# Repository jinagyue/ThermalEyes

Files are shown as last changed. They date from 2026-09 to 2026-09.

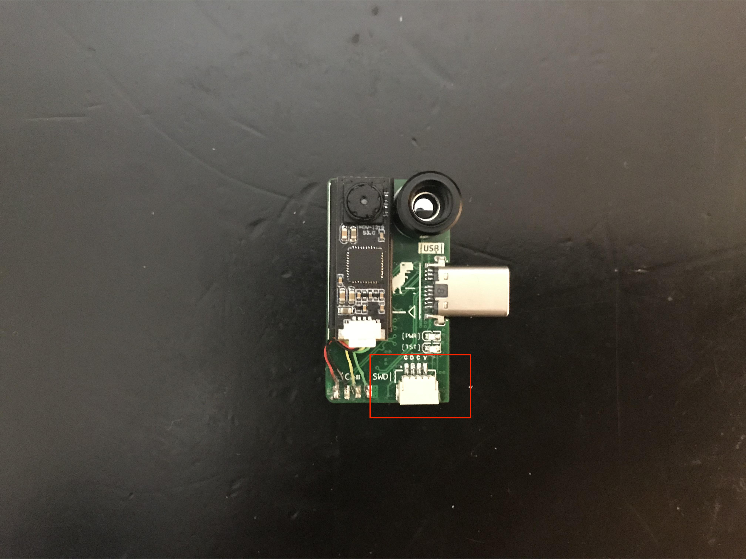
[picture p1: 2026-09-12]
firmware/Resource/port.png

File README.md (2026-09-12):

# ThermalEyes (双目手机红外热成像系统)

<div align="center">







**一款集可见光与远红外热辐射于一体的双光谱手机热成像开源套件**  
*支持实时双光图像融合、视差校准补偿、伪彩映射与高低温动态跟踪*

</div>

---

## 📖 项目简介 (Overview)

**ThermalEyes** 是一个软硬件结合的全栈开源项目。项目通过外接便携式双目模组（可见光摄像头 + MLX90640 远红外传感器），在 Android 移动端实现双光融合成像。借助 C++ (OpenCV) 原生算法，将可见光的丰富高频细节与红外热辐射轮廓实时叠加，解决红外分辨率低、轮廓模糊的问题。

本项目采用 **Monorepo（单一大仓库）** 结构，包含**下位机固件**、**Android 客户端应用**以及**3D 打印外壳模型**。

---

## 🗂️ 仓库目录结构 (Repository Structure)

```text
ThermalEyes/
├── software/                 # Android 手机客户端源码
│   ├── app/                  # 主 APP 模块 (Java UI + NDK C++ 融合算法)
│   ├── OpenCV/               # OpenCV Android SDK 模块
│   └── build.gradle          # Gradle 构建配置
│
├── firmware/                 # STM32 下位机桥接固件源码
│   ├── Core/                 # STM32 主逻辑与系统配置
│   ├── Hardware/             # MLX90640 I2C 驱动与温度解析算法
│   ├── USB_DEVICE/           # USB CDC 虚拟串口通讯协议
│   └── thermal_bridge.ioc    # STM32CubeMX 工程配置文件
│
├── hardware/                 # 硬件外壳结构设计
│   ├── *.STL                 # 3D 打印成型切片模型 (顶盖与底座)
│   └── *.STEP                # CAD 三维结构工程源文件
│
├── .gitignore                # 统合过滤编译输出与环境配置
└── README.md                 # 项目说明文档
```

---

## 🛠️ 系统架构与数据链路 (System Architecture)

```mermaid
graph LR
    subgraph HW["硬件端 (Hardware)"]
        MLX["MLX90640 红外传感器<br/>(32x24 热阵列)"] -->|I2C 400kHz| MCU["STM32F411CEU6<br/>(固件: firmware)"]
        MCU -->|USB CDC 数据流| HUB["Type-C OTG 接口"]
        CAM["可见光 UVC 摄像头模组"] -->|USB Video| HUB
    end

    subgraph APP["手机端 (Android / software)"]
        HUB --> USB_MGR["Android USB Host"]
        USB_MGR -->|UVCAndroid 协议| FRAME_CAM["可见光视频帧"]
        USB_MGR -->|UsbSerial 串口驱动| FRAME_IR["红外原始温度帧"]
        
        FRAME_CAM --> FUSION["C++ OpenCV 图像融合引擎<br/>(视差校准 + 高频增强 + 伪彩映射)"]
        FRAME_IR --> FUSION
        FUSION --> GL_VIEW["实时 HUD 显示 & 高低温跟踪"]
    end
```

---

## 📋 硬件物料清单 (Hardware BOM)

| 部件类别 | 型号 / 规格 | 说明 |
| :--- | :--- | :--- |
| **主控芯片** | STM32F411CEU6 (BlackPill 或定制板) | 运行 `firmware/` 固件，解析 MLX90640 并通过 USB CDC 上传 |
| **红外热传感器** | MLX90640 (常用 55° 或 110° 视场角) | 32×24 像素阵列远红外传感器，I2C 通讯 |
| **可见光相机** | UVC 协议免驱 USB 摄像头模组 | 与红外传感器等间距并排安装 |
| **连接外壳** | 3D 打印外壳 (`hardware/` 目录) | 建议使用 PETG 或树脂 3D 打印，双镜头固定 |
| **通讯接口** | Type-C 数据线 / OTG 转换器 | 连接至 Android 手机 USB-C 口 |

---

## 🚀 快速上手与复刻指南 (Getting Started)

### 1. 固件烧录 (`firmware/`)
- **开发工具**：STM32CubeIDE (推荐 v1.13.0+)
- **烧录接口**：采用 **SH1.0 4-Pin SWD 接口**，线序如下（供电 3.3V）：
  ```text
  | GND | SWDIO | SWCLK | 3.3V |
  ```
- **编译与烧录**：
  1. 使用 STM32CubeIDE 打开 `firmware/` 目录作为工程。
  2. 连接 ST-Link 或 DAP-Link 调试器。
  3. 执行 `Project -> Build Project`，点击 Run/Debug 将固件烧录进 STM32。

### 2. Android 客户端构建 (`software/`)
- **开发工具**：Android Studio (推荐 Bumblebee 或更新版本)
- **依赖环境**：Android SDK、NDK (Side-by-side)、CMake
- **构建步骤**：
  1. 使用 Android Studio 打开 `software/` 目录。
  2. 等待 Gradle 同步完成（若提示 NDK/CMake 缺失请根据提示在 SDK Manager 中安装）。
  3. 连接支持 OTG 功能的 Android 手机，开启开发者选项与 USB 调试。
  4. 点击 **Run 'app'** 安装至手机。

### 3. 外壳制作 (`hardware/`)
- 使用 3D 打印切片软件（如 Cura、Bambu Studio、PrusaSlicer）导入 `hardware/` 目录下的 `.STL` 文件：
  - `binocular_thermal_imager - bottom-2.STL`（下盖）
  - `binocular_thermal_imager - top-2.STL`（上盖）
- **打印建议**：层高 0.16mm - 0.2mm，填充率 30% 以上。

---

## ✨ 核心功能与使用特性 (Features)

1. **双光谱实时融合**：
   - 采用拉普拉斯/高斯滤波提取可见光高频轮廓，与热分布底图融合，实现细节丰富的高清热成像。
2. **多模式切换**：
   - 支持纯可见光、纯红外热成像、轮廓画中画、双光叠加融合模式。
3. **视差动态校准 (Parallax Correction)**：
   - 算法内置水平与垂直平移补偿调节，消除不同测距下双镜头物理间距造成的图像重影。
4. **多样化伪彩映射 (Colormaps)**：
   - 支持 Ironbow（铁红）、Rainbow（彩虹）、JET、White Hot、Black Hot 等主流热成像调色板。
5. **动态高低温标记**：
   - 实时自动检测全屏最高温、最低温坐标，并自动跟随绘制十字准星与数值。

---

## 📄 许可证 (License)

本项目基于 [MIT License](software/LICENSE) 开源。欢迎 Star、Fork 并提交 Pull Request！

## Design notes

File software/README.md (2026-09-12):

# ThermalEyes
双目热成像手机APP，用于获取摄像头数据和热成像数据，并进行融合显示

## Environment
Android Studio Bumblebee | 2021.1.1 Patch 2

## Test Platform
meizu 18s

## Depends on
 - [UVCAndroid](https://github.com/shiyinghan/UVCAndroid)
 - [UsbSerial](https://github.com/felHR85/UsbSerial)

## Structure
```
 |- app  // APP Demo, 冒烟基于该app
 |- app2 // 存在问题，未启用
```

## Feature
1. 获取热成像数据
2. 获取摄像头数据
3. 图像融合
4. 图像显示
5. 融合模式切换
6. 伪彩颜色空间切换
7. 算法参数调整（视差补偿、高频占比）
8. 高低温跟踪和显示
9. 显示下位机log
10. 保存用户配置(TODO)
11. 热成像帧率调整
12. 拍照(TODO)
13. 后期分析(TODO)
    
## Development
由于 Android 手机 USB 端口被占用，需要使用 WIFI 无线调试，开启方法如下：

1. 使用 USB 线将手机连接电脑，开启USB调试，在 Android Studio 中的 Terminal 窗口输入`adb devices`能看到设备
2. 保证电脑和手机在同一个局域网下，然后输入命令`adb tcpip 5555`开启手机远程调试功能
3. 找到手机的IP地址，执行命令`adb connect <IP>`进行远程连接
4. 最后断开手机USB连接，执行命令`adb devices`能看到设备既已经连接
    
## Change Log
20231128 
 - 完成基本功能

20231209
 - 集成OpenCV
 - 改用高斯模糊提取高频信息
 - 增加视差调整功能

20231221
 - 增加高低温跟踪
 - 增加菜单栏算法参数配置
 - 屏幕旋转锁定
 - 修改下位机通信协议

20230203
 - 增加热成像帧率调整选项
 - camera连接时打开热成像，删除打开关闭按钮
 - 优化软件界面
 - 适配3d外壳的视差调整
 - 修复第二次插入闪退问题

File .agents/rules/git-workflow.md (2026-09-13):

# Git 更新规范 (Git Workflow Rules)

## 核心规则 (Mandatory Rule)
**每次处理、修改代码或完成问题排查后，都必须更新 Git！**
Whenever any code is processed, bug fixed, or feature modified, the agent MUST update Git.

## 执行流程 (Execution Steps)
1. **核对改动**：运行 `git status` 与 `git diff` 审查修改内容，确保无多余临时文件或不相关改动。
2. **暂存文件**：执行 `git add <files>` 暂存修改及新增的相关文件。
3. **清晰提交**：执行 `git commit -m "<type>(<scope>): <message>"`，使用清晰的中文或英文语义化提交信息。
4. **工作区检查**：确认 `git status` 确保工作区状态符合预期。

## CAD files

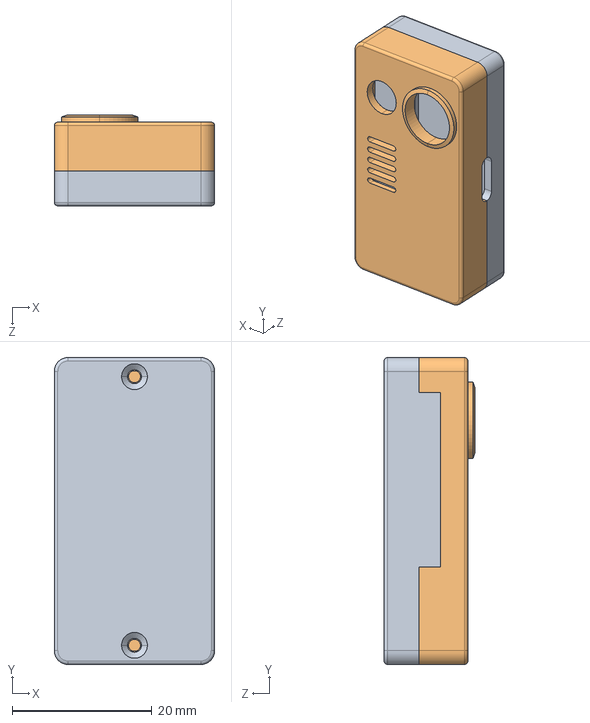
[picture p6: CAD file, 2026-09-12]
hardware/binocular_thermal_imager.STEP
23.0 x 44.0 x 13.0 mm
bottom
top

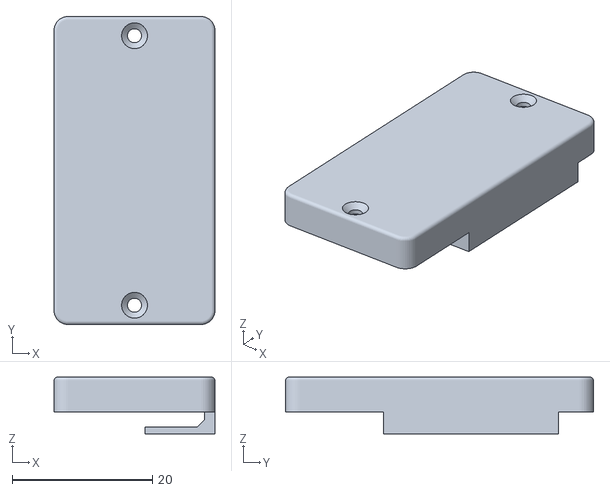
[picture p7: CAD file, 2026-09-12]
hardware/binocular_thermal_imager - bottom-2.STL
23.0 x 44.0 x 8.10

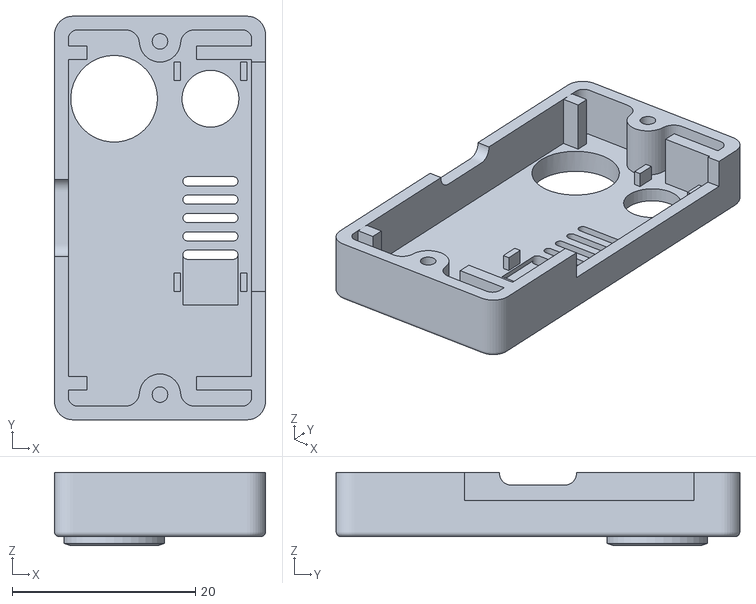
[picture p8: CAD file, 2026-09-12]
hardware/binocular_thermal_imager - top-2.STL
23.0 x 44.0 x 8.00

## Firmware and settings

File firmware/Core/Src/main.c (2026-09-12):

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
/* Includes ------------------------------------------------------------------*/
#include "main.h"
#include "i2c.h"
#include "usart.h"
#include "usb_device.h"
#include "gpio.h"

/* USER CODE BEGIN Includes */
#include "mlx90640_adapter.h"
#include "usb_data_transfer.h"
#include "common.h"
/* USER CODE END Includes */


/* USER CODE BEGIN PV */
static float g_thermal_data[MLX90640_PIXEL_NUM];
/* USER CODE END PV */

void SystemClock_Config(void);
/* USER CODE BEGIN 0 */
#ifdef __GNUC__
#define PUTCHAR_PROTOTYPE int __io_putchar(int ch)
#else
#define PUTCHAR_PROTOTYPE int fputc(int ch, FILE *f)
#endif

PUTCHAR_PROTOTYPE
{
  HAL_UART_Transmit(&huart2, (uint8_t *)&ch, 1, HAL_MAX_DELAY);
  return ch;
}
/* USER CODE END 0 */

/**
  * @brief  The application entry point.
  * @retval int
  */
int main(void)
{
  /* USER CODE BEGIN 1 */
  uint32_t cnt = 0;
  uint8_t fast_mode = 1;
  /* USER CODE END 1 */

  /* MCU Configuration--------------------------------------------------------*/

  /* Reset of all peripherals, Initializes the Flash interface and the Systick. */
  HAL_Init();

  /* Configure the system clock */
  SystemClock_Config();

  /* Initialize all configured peripherals */
  MX_GPIO_Init();
  MX_I2C1_Init();
  MX_USART2_UART_Init();
  MX_USB_DEVICE_Init();
  /* USER CODE BEGIN 2 */
  mlx_param_init();
  praw("mlx init ok\r\n");
  usb_transfer_init();
  /* USER CODE END 2 */

  /* Infinite loop */
  /* USER CODE BEGIN WHILE */
  while (1)
  {
    /* USER CODE END WHILE */

    /* USER CODE BEGIN 3 */
	int ret;
	usb_control_cmd usb_cmd;

	ret = usb_get_cmd(&usb_cmd);
	if (ret > 0) {
		perr("usb cmd: type(%d), fps(%d)", usb_cmd.type, usb_cmd.fps);
		if (usb_cmd.type == USB_DATA_TYPE_CMD_FPS) {
			(void)mlx_set_refresh_rate(usb_cmd.fps);
		}
	}

	mlx_data_read(g_thermal_data);

#if 0
	praw("=================== %ld ======================\r\n", cnt++);
	for (int i = 12; i < 13; i++) {
	  for (int j = 0; j < MLX90640_COLUMN_NUM; j++) {
		praw("%02.2f ", g_thermal_data[i * MLX90640_COLUMN_NUM + j]);
	  }
      praw("\r\n");
	}
	praw("=========================================\r\n");
#endif

	ret = usb_data_store_f(g_thermal_data, count_of(g_thermal_data));
	if (ret != 0) {
	  return ret;
	}
	usb_data_send();

	if (HAL_GPIO_ReadPin(GPIOA, GPIO_PIN_0) == GPIO_PIN_RESET) {
		while (HAL_GPIO_ReadPin(GPIOA, GPIO_PIN_0) != GPIO_PIN_SET) {
			HAL_Delay(1);
		}
		fast_mode = (fast_mode == 0 ? 1 : 0);
	}

	if (fast_mode == 1) {
		HAL_GPIO_WritePin(GPIOC, GPIO_PIN_13, GPIO_PIN_RESET);
	} else {
		HAL_GPIO_WritePin(GPIOC, GPIO_PIN_13, GPIO_PIN_SET);
		HAL_Delay(1000);
	}
  }
  /* USER CODE END 3 */
}

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


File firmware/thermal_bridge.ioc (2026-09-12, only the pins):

Mcu.UserName=STM32F411CEUx
PA0-WKUP.Signal=GPIO_Input
PA11.Signal=USB_OTG_FS_DM
PA12.Signal=USB_OTG_FS_DP
PA2.Signal=USART2_TX
PA3.Signal=USART2_RX
PB6.Signal=I2C1_SCL
PB7.Signal=I2C1_SDA
PC13-ANTI_TAMP.Signal=GPIO_Output

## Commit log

2026-09-12 feat: initial commit for monorepo (software, firmware, hardware)
    [binocular_thermal_imager - bottom-2.STL, binocular_thermal_imager - top-2.STL, binocular_thermal_imager.STEP]
2026-09-13 feat(agent): 新增 .agents 规范与每次处理自动更新 Git 规则，优化光轴自动对齐算法视差搜索区间
2026-09-13 feat(alignment): add physics-constrained depth-aware registration
    - 重构光轴配准为逆深度物理视差模型 dx(Z)=ax/Z+bx，废除无物理约束的二维自由搜索
    - 热像优先在原生 32x24 尺度完成 Otsu 分割与可观测性检验，检测满视野溢出 (ALIGN_TARGET_CLIPPED)
    - 可见光构建高斯平滑连续距离场，采用 Chamfer 轮廓距离匹配
    - 粗精两级多尺度匹配 (160x120 全局逆深度 + 320x240 局部精修)
    - 增加峰值唯一性、PSR 旁瓣比三重置信度与边界命中防护 (ALIGN_RANGE_LIMITED)
    - JNI 扩展返回结构化状态码与物距、置信度，运行时视差与持久标定解耦
2026-09-13 fix(metering): align center temperature reticle with thermal geometry
    - 在 FrameInfo 中增加 centerLoc 空间定位点，与 MAX/MIN 保持一致空间映射
    - MainActivity 绘制 CTR 中心十字时使用映射后的坐标与缩放比例
    - 修复智能对齐后覆盖持久化标定的缺陷，改为仅更新运行时动态视差与物距
2026-09-13 fix(alignment): lower thermal segmentation floor to include cooler fingers in target contour

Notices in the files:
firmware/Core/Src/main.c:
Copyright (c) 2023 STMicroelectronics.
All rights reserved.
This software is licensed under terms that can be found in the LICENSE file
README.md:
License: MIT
